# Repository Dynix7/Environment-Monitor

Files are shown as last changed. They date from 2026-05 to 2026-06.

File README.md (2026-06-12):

# Environment-Monitor
This is a board that serves as an environment sensor, recording the temperature, humidity, air pressure, brightness, and air quality of the area around it. It does this through the use of 5 sensors: TMP102AIDR, AHT20-F, BMP388, LTR303, and AGS10. The information can be displayed of the built in SSD1306 0.91 screen.
# Why I Made It
Not surprisingly I spend a lot of time sitting indoors in my room on my computer.  With this, I often have my door closed and sometimes the window open. I wanted a device that can monitor my room so I can make optimize my environment so if it detects that it's getting to hot (for example) I can open the window more or open my door. 

# Pictures

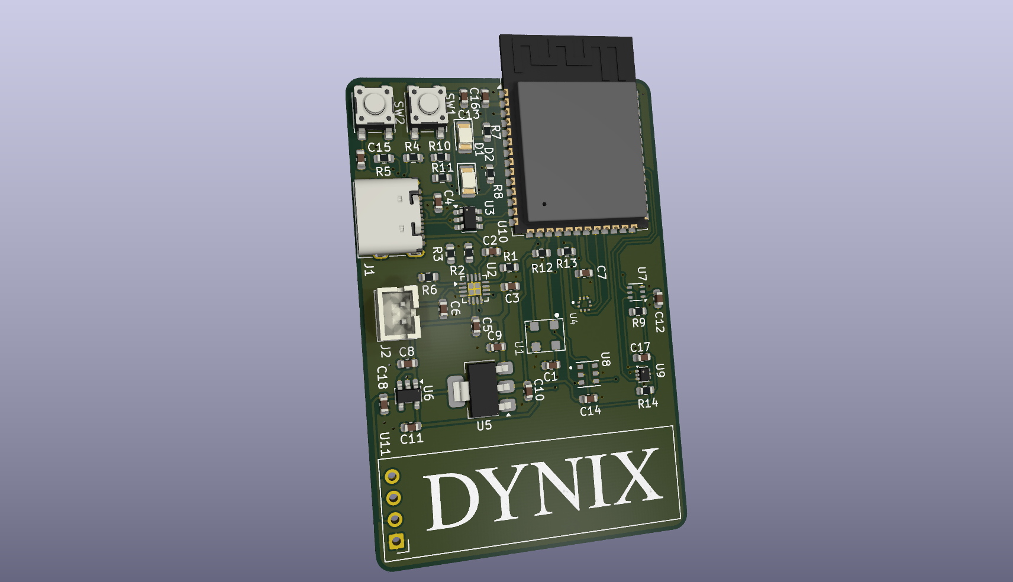
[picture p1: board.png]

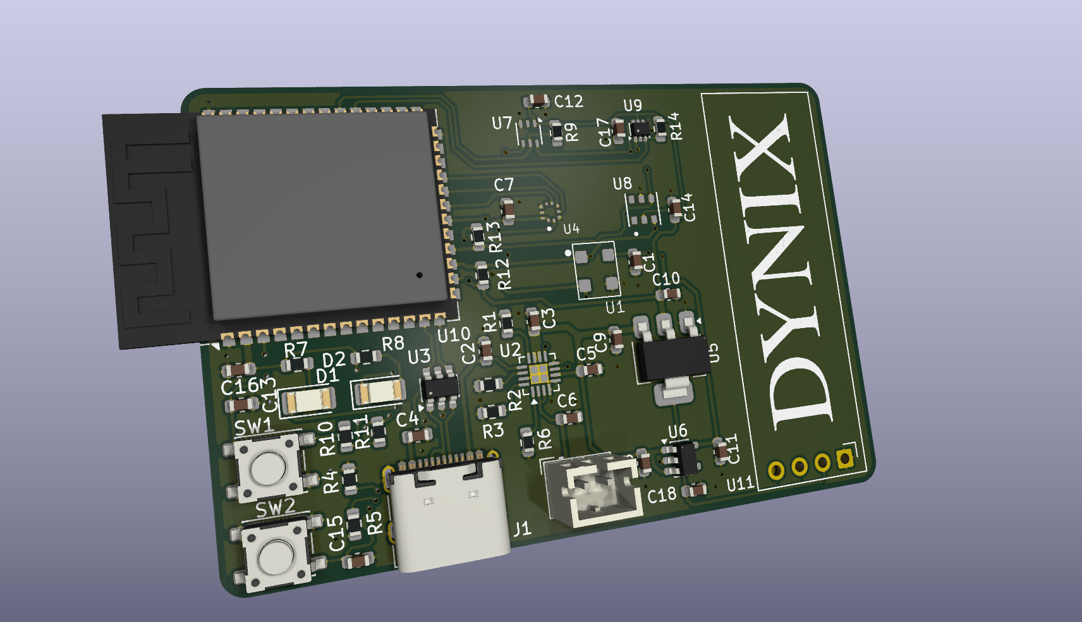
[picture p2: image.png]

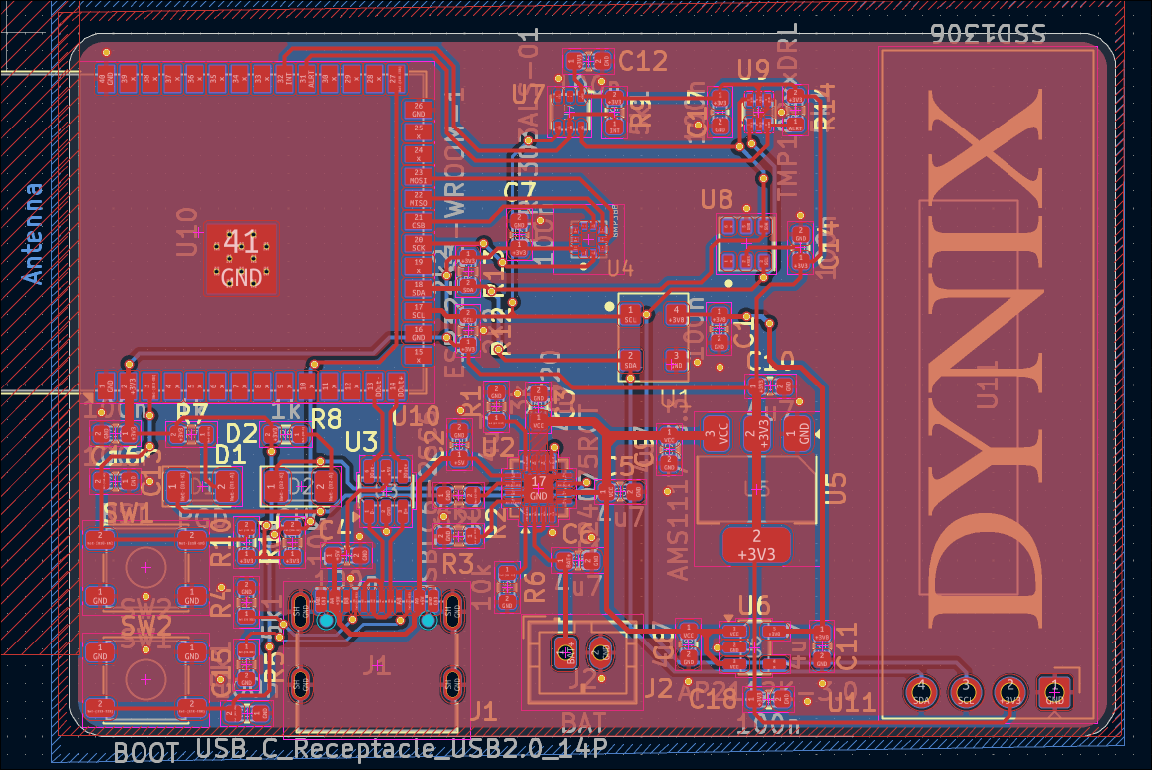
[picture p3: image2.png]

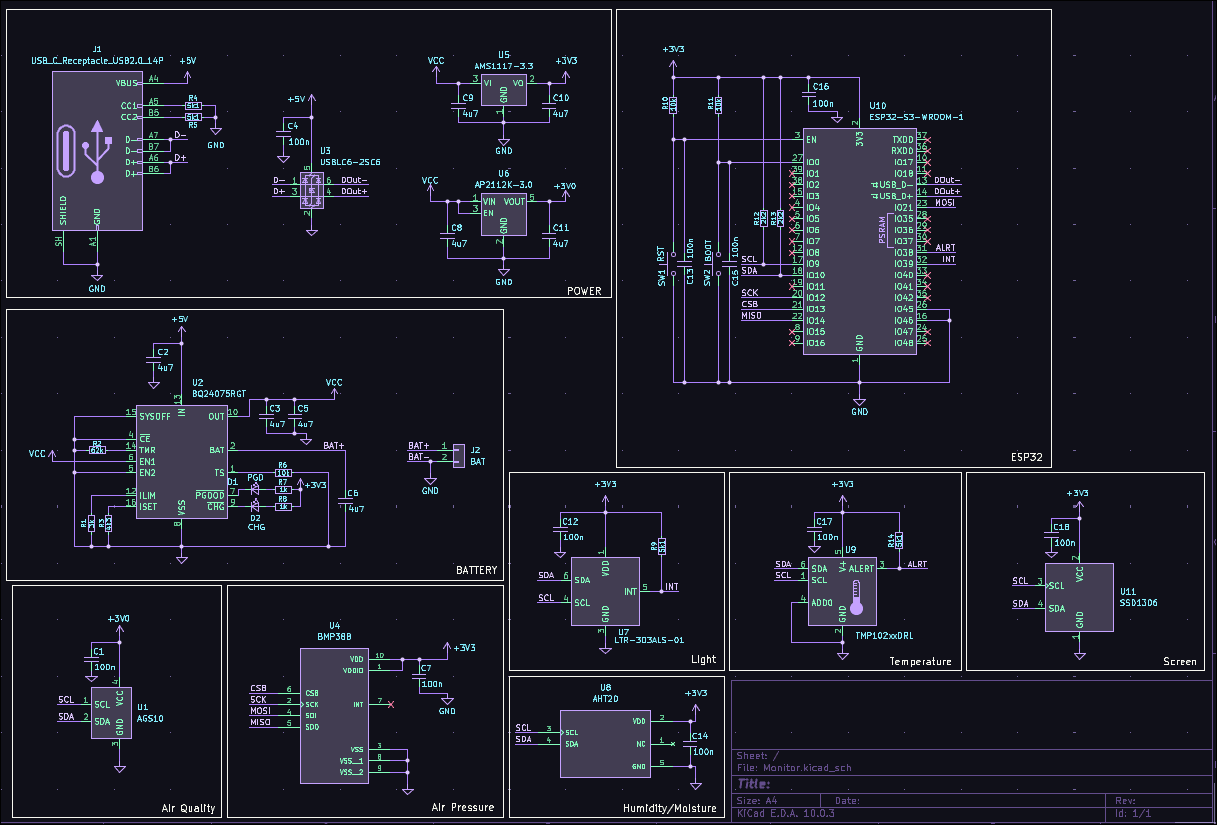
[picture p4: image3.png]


# BOM
|Name |Purpose |Quantity|Total Cost (USD)|Link |Distributor|
|---|---|---|---|---|---|
|3.7v Battery |Power when not plugged in | |6.57 |https://www.aliexpress.us/item/3256811644617885.html |Aliexpress |
|SSD1306 Display  |Displaying Measured Stats | |2.20 |https://www.aliexpress.us/item/3256808453793642.html |Aliexpress |
|JST Connector |Battery Connector | |0.67 |https://www.lcsc.com/product-detail/C131337.html |LCSC |
|USB C Receptacle |Programming and Power | |0.41 |https://www.lcsc.com/product-detail/C2988369.html |LCSC |
|4.3k Resistor |Configuration Resistor | |0.11 |https://www.lcsc.com/product-detail/C2930099.html |LCSC |
|62k Resistor |Configuration Resistor | |0.11 |https://www.lcsc.com/product-detail/C2907059.html |LCSC |
|3k Resistor |Configuration Resistor For BQ24075| |0.12 |https://www.lcsc.com/product-detail/C2907033.html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|LCSC |
|2.2k Resistor |I2C Pullups | |0.10 |https://www.lcsc.com/product-detail/C2907117.html |LCSC |
|1k Resistor |For LEDs | |0.10 |https://www.lcsc.com/product-detail/C2907002.html |LCSC |
|10k Resistor |Pull Ups | |0.10 |https://www.lcsc.com/product-detail/C2930027.html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|LCSC |
|5.1k Resistor |For USB CC1 and CC2 | |0.10 |https://www.lcsc.com/product-detail/C2907114.html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|LCSC |
|4.7uF Capacitor  |Decoupling Capacitor | |0.30 |https://www.lcsc.com/product-detail/C8032.html |LCSC |
|100nF Resistor |Decoupling | |0.25 |https://www.lcsc.com/product-detail/C5137636.html |LCSC |
|USBLC6-2SC6 |Protection for USB | |0.16 |https://www.lcsc.com/product-detail/C5261088.html |LCSC |
|BQ24075RGTR |Power Path and Battery Charging | |1.05 |https://www.lcsc.com/product-detail/C15464.html |LCSC |
|TPAP2112K-3.0TRG1|Power Regulator for AGS10 | |0.35 |https://www.lcsc.com/product-detail/C23380903.html |LCSC |
|AMS1117-3.3 |Power Regulator | |0.42 |https://www.lcsc.com/product-detail/C347222.html |LCSC |
|LTR-303ALS-01 |Light Sensor | |0.41 |https://www.lcsc.com/product-detail/C364577.html |LCSC |
|AGS10 |TVOC/Air Quality Sensor | |1.59 |https://www.lcsc.com/product-detail/C3012632.html |LCSC |
|BMP388 |Air Pressure Sensor | |2.81 |https://www.lcsc.com/product-detail/C779278.html |LCSC |
|TMP102AIDRLR |Accurate Temperature Sensor | |1.27 |https://www.lcsc.com/product-detail/C99269.html |LCSC |
|AHT20-F |Humidity Sensor |1 |0.76 |https://www.lcsc.com/product-detail/C3012622.html |LCSC |
|ESP32-S3 |Microcontroller for board |1 |5.25 |https://www.lcsc.com/product-detail/C2913205.html |LCSC |
|Stencil |Help With Soldering | |7.11 | |JLCPCB |
|PCB |Place Components On | |5.11 | |JLCPCB |

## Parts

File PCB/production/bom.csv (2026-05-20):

Designator | Footprint | Quantity | Value | LCSC Part #
C1, C12, C13, C14, C15, C16, C17, C18, C4, C7 | 0603 | 10 | 100n
C10, C11, C2, C3, C5, C6, C8, C9 | 0603 | 8 | 4u7
D1 | 1206 | 1 | PGD
D2 | 1206 | 1 | CHG
J1 | USB_C_Receptacle_G-Switch_GT-USB-7010ASV | 1 | USB_C_Receptacle_USB2.0_14P
J2 | JST_PH_B2B-PH-K_1x02_P2.00mm_Vertical | 1 | BAT
R1 | 0603 | 1 | 3k
R10, R11, R6 | 0603 | 3 | 10k
R12, R13 | 0603 | 2 | 2k2
R14, R4, R5, R9 | 0603 | 4 | 5k1
R2 | 0603 | 1 | 62k
R3 | 0603 | 1 | 4k3
R7, R8 | 0603 | 2 | 1k
SW1 | SW_SPST_PTS647_Sx38 | 1 | RST
SW2 | SW_SPST_PTS647_Sx38 | 1 | BOOT
U1 | AGS10 | 1 | AGS10
U10 | ESP32-S3-WROOM-1 | 1 | ESP32-S3-WROOM-1
U11 | ER_OLEDM0.91_1x-I2C | 1 | SSD1306
U2 | VQFN-16-1EP_3x3mm_P0.5mm_EP1.6x1.6mm | 1 | BQ24075RGT
U3 | SOT-23-6 | 1 | USBLC6-2SC6
U4 | XDCR_BMP388 | 1 | BMP388
U5 | SOT-223-3_TabPin2 | 1 | AMS1117-3.3
U6 | SOT-23-5 | 1 | AP2112K-3.0
U7 | Lite-On_LTR-303ALS-01 | 1 | LTR-303ALS-01
U8 | PSON100P300X300X110-6N | 1 | AHT20
U9 | SOT-563 | 1 | TMP102xxDRL

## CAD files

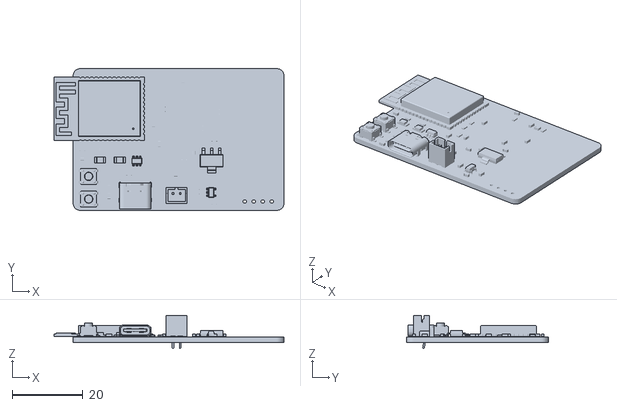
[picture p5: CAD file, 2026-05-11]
pcb.stl
64.9 x 40.0 x 9.40

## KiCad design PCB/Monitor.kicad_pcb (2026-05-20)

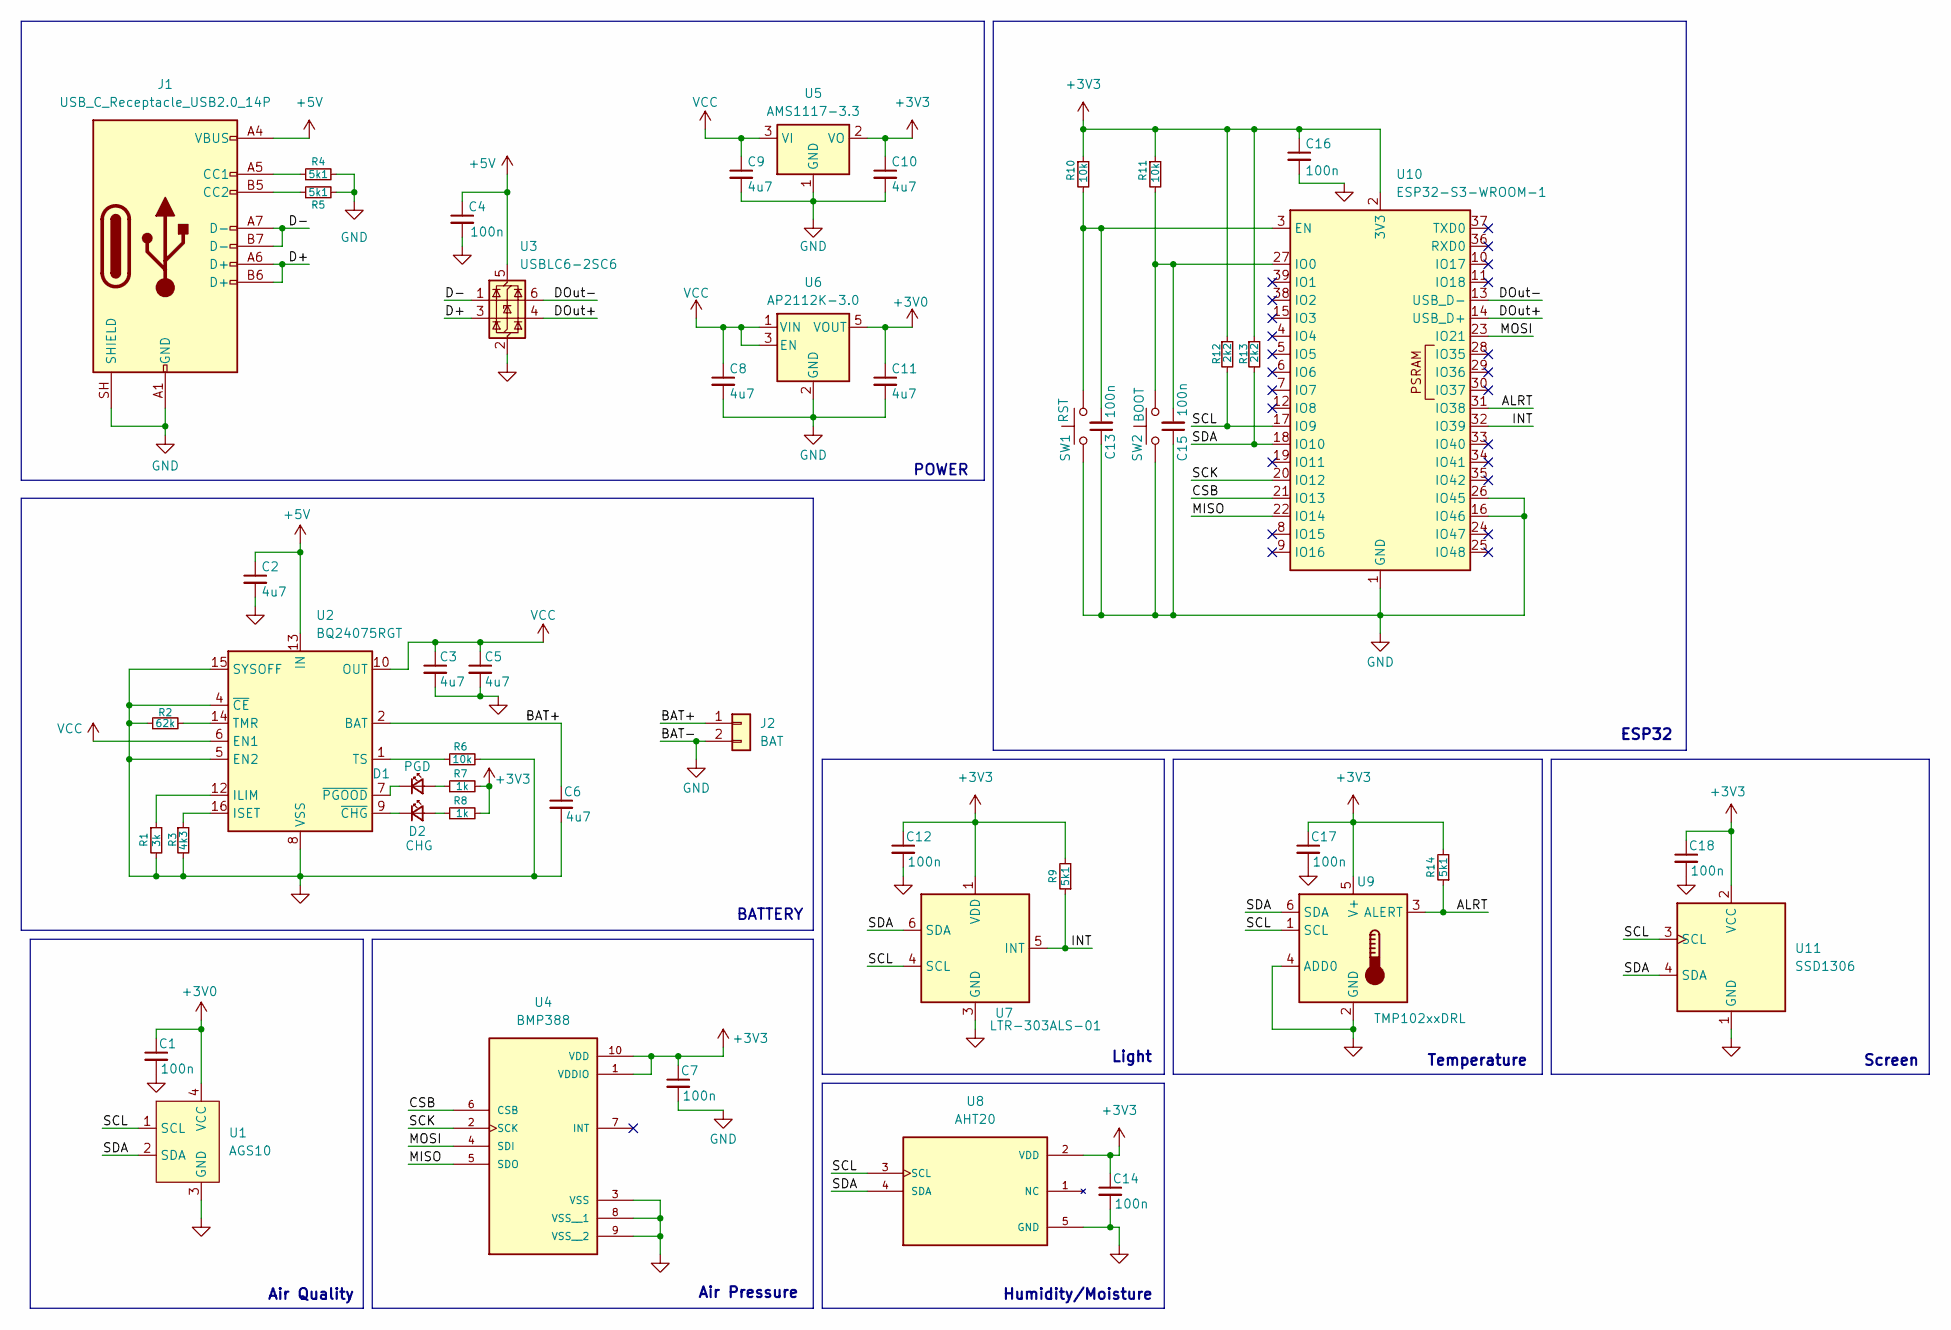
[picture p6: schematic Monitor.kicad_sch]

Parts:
C1, C4, C7, C12, C13, C14, C15, C16, C17, C18: 100n; C_0603_1608Metric
C2, C3, C5, C6, C8, C9, C10, C11: 4u7; C_0603_1608Metric
D1: PGD; LED_1206_3216Metric
D2: CHG; LED_1206_3216Metric
J1: USB_C_Receptacle_USB2.0_14P; USB_C_Receptacle_G-Switch_GT-USB-7010ASV
J2: BAT; JST_PH_B2B-PH-K_1x02_P2.00mm_Vertical
R1: 3k; R_0603_1608Metric
R2: 62k; R_0603_1608Metric
R3: 4k3; R_0603_1608Metric
R4, R5, R9, R14: 5k1; R_0603_1608Metric
R6, R10, R11: 10k; R_0603_1608Metric
R7, R8: 1k; R_0603_1608Metric
R12, R13: 2k2; R_0603_1608Metric
SW1: RST; SW_SPST_PTS647_Sx38
SW2: BOOT; SW_SPST_PTS647_Sx38
U1: AGS10
U2: BQ24075RGT; VQFN-16-1EP_3x3mm_P0.5mm_EP1.6x1.6mm
U3: USBLC6-2SC6; SOT-23-6
U4: BMP388; XDCR_BMP388; PARTREV 1.7
U5: AMS1117-3.3; SOT-223-3_TabPin2
U6: AP2112K-3.0; SOT-23-5
U7: LTR-303ALS-01; Lite-On_LTR-303ALS-01
U8: AHT20; PSON100P300X300X110-6N; PARTREV V1.0
U9: TMP102xxDRL; SOT-563
U10: ESP32-S3-WROOM-1
U11: SSD1306; ER_OLEDM0.91_1x-I2C

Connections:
+3V0: C1.1, C11.1, U1.4 (VCC), U6.5 (VOUT)
+3V3: C7.1, C10.1, C12.1, C14.1, C16.1, C17.1, C18.1, R7.2, R8.2, R9.2, R10.1, R11.1, R12.1, R13.1, R14.2, U4.1 (VDDIO), U4.10 (VDD), U5.2 (VO), U7.1 (VDD), U8.2 (VDD), U9.5 (V+), U10.2 (3V3), U11.2 (VCC)
+5V: C2.1, C4.1, J1.A4 (VBUS), J1.A9 (VBUS), J1.B4 (VBUS), J1.B9 (VBUS), U2.13 (IN), U3.5 (VBUS)
/ALRT: R14.1, U9.3 (ALERT), U10.31 (IO38)
/BAT+: C6.1, J2.1, U2.2 (BAT), U2.3 (BAT)
/CSB: U4.6 (CSB), U10.21 (IO13)
/D+: J1.A6 (D+), J1.B6 (D+), U3.3 (I/O2)
/D-: J1.A7 (D-), J1.B7 (D-), U3.1 (I/O1)
/DOut+: U3.4 (I/O2), U10.14 (USB_D+)
/DOut-: U3.6 (I/O1), U10.13 (USB_D-)
/INT: R9.1, U7.5 (INT), U10.32 (IO39)
/MISO: U4.5 (SDO), U10.22 (IO14)
/MOSI: U4.4 (SDI), U10.23 (IO21)
/SCK: U4.2 (SCK), U10.20 (IO12)
/SCL: R12.2, U1.1 (SCL), U7.4 (SCL), U8.3 (SCL), U9.1 (SCL), U10.17 (IO9), U11.3 (SCL)
/SDA: R13.2, U1.2 (SDA), U7.6 (SDA), U8.4 (SDA), U9.6 (SDA), U10.18 (IO10), U11.4 (SDA)
GND: C1.2, C2.2, C3.2, C4.2, C5.2, C6.2, C7.2, C8.2, C9.2, C10.2, C11.2, C12.2, C13.1, C14.2, C15.1, C16.2, C17.2, C18.2, J1.A1 (GND), J1.A12 (GND), J1.B1 (GND), J1.B12 (GND), J1.SH (SHIELD), J2.2, R1.2, R2.1, R3.2, R4.2, R5.2, R6.2, SW1.1, SW2.1, U1.3 (GND), U2.4 (~CE), U2.5 (EN2), U2.8 (VSS), U2.15 (SYSOFF), U2.17 (VSS), U3.2 (GND), U4.3 (VSS), U4.8 (VSS__1), U4.9 (VSS__2), U5.1 (GND), U6.2 (GND), U7.3 (GND), U8.5 (GND), U9.2 (GND), U9.4 (ADD0), U10.1 (GND), U10.16 (IO46), U10.26 (IO45), U10.40 (GND), U10.41 (GND), U11.1 (GND)
unnamed: D1.2 (A), R7.1
unnamed: D1.1 (K), U2.7 (~PGOOD)
unnamed: D2.2 (A), R8.1
unnamed: D2.1 (K), U2.9 (~CHG)
unnamed: J1.A5 (CC1), R4.1
unnamed: J1.B5 (CC2), R5.1
unnamed: R1.1, U2.12 (ILIM)
unnamed: R3.1, U2.16 (ISET)
unnamed: R2.2, U2.14 (TMR)
unnamed: R6.1, U2.1 (TS)
unnamed: C13.2, R10.2, SW1.2, U10.3 (EN)
unnamed: C15.2, R11.2, SW2.2, U10.27 (IO0)
VCC: C3.1, C5.1, C8.1, C9.1, U2.6 (EN1), U2.10 (OUT), U2.11 (OUT), U5.3 (VI), U6.1 (VIN), U6.3 (EN)

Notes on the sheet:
Screen
Humidity/Moisture
Light
Air Pressure
ESP32
Air Quality
POWER
BATTERY
Temperature

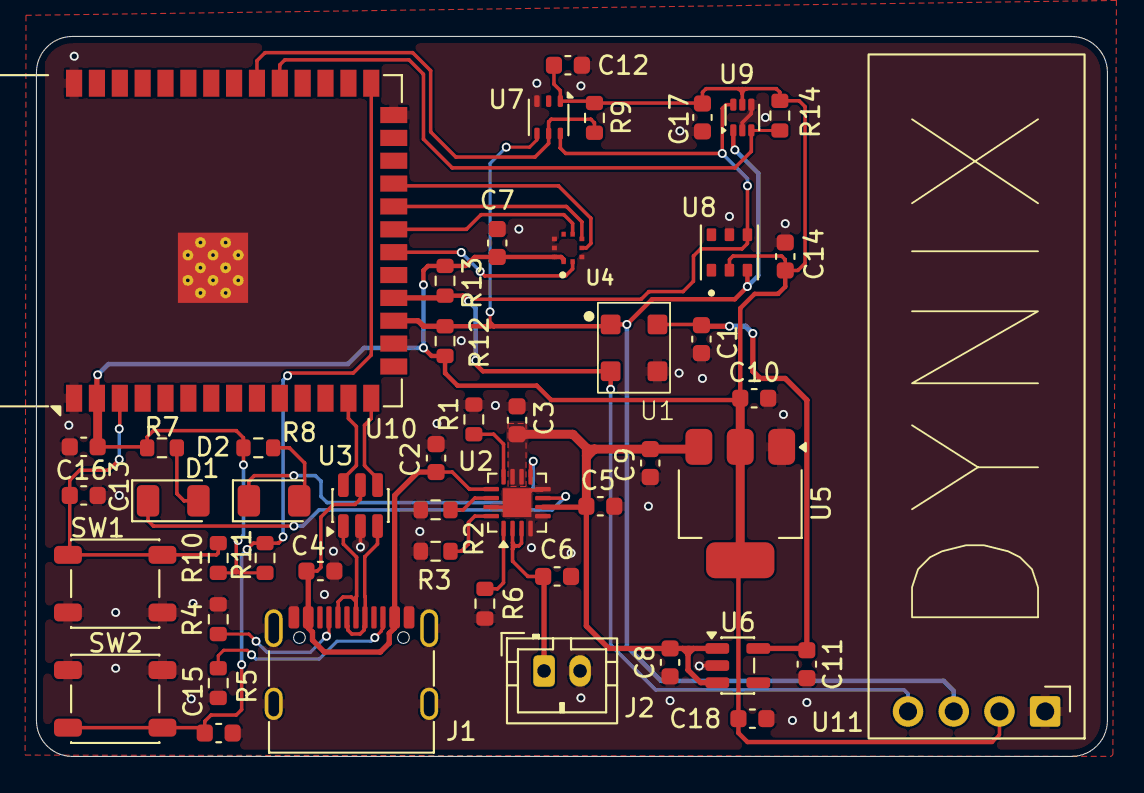
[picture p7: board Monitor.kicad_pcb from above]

Board: 2 copper layers, 59.5 x 40.0 mm, 49 parts (0 on the bottom side), 30 nets.

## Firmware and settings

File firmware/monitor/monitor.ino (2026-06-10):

#include <Arduino.h>
#include <Wire.h>

#include <AGS10.h>
#include <Adafruit_SSD1306.h>
#include <Adafruit_Sensor.h>
#include "Adafruit_BMP3XX.h"
#include <Adafruit_AHTX0.h>
#include "Adafruit_LTR329_LTR303.h"
#include <SparkFunTMP102.h>


#include "config.hpp"

struct totalData data;


Adafruit_SSD1306 SCREEN(SCREEN_WIDTH, SCREEN_HEIGHT, SCREEN_WIRE, OLED_RESET);
AGS10 AGSSensor = AGS10();
Adafruit_BMP3XX BMPSensor;
Adafruit_AHTX0 AHT20;
Adafruit_LTR303 LTR = Adafruit_LTR303();
TMP102 TMP;

// Prototypes
void initScreen();
void updateScreen();

void initAGS();
void initBMP();
void initAHT();
void initLTR();
void initTMP();

void readAllData();



void setup() {
    Serial.begin(115200);

    pinMode(CSB, OUTPUT);
    pinMode(ALRT, INPUT);
    
    Wire.begin(SDA_PIN, SCL_PIN);
    Wire.setClock(400000);


    initScreen();

    initAGS();
    initBMP();
    initAHT();
    initLTR();
    initTMP();
}


void loop() {
    readAllData();
    updateScreen();

    delay(2000);
}

void initScreen() {
    SCREEN.begin(SSD1306_SWITCHCAP, SCREEN_ADDRESS);
    SCREEN.clearDisplay();
    SCREEN.setTextSize(2);
    SCREEN.setTextColor(SSD1306_WHITE);

    SCREEN.print("Starting...");
    SCREEN.display();
}

void updateScreen() {
    SCREEN.clearDisplay();
    SCREEN.setTextSize(1);
    SCREEN.setCursor(0, 0);

    SCREEN.print("Temperature: ");
    SCREEN.println(data.temperature);

    SCREEN.print("Humidity: ");
    SCREEN.println(data.humidity);

    SCREEN.print("TVOC: ");
    SCREEN.println(data.TVOC);

    SCREEN.print("Pressure: ");
    SCREEN.println(data.pressure);

    SCREEN.print("Altitude: ");
    SCREEN.println(data.altitude);

    SCREEN.print("Visible + IR: ");
    SCREEN.println(data.visbleAndIR);

    SCREEN.print("IR: ");
    SCREEN.println(data.IR);

    SCREEN.display();
}

void initAGS() {
    AGSSensor.begin();
    AGSSensor.calibrateFact();
}

void initBMP() {
    if(!BMPSensor.begin_SPI(CSB, SCK, MISO, MOSI)) {
        Serial.print("BMP Error");
    }

    BMPSensor.setTemperatureOversampling(BMP3_OVERSAMPLING_8X);
    BMPSensor.setPressureOversampling(BMP3_OVERSAMPLING_4X);
    BMPSensor.setIIRFilterCoeff(BMP3_IIR_FILTER_COEFF_3);
    BMPSensor.setOutputDataRate(BMP3_ODR_50_HZ);
}

void initAHT() {
    if (!AHT20.begin()) {
        Serial.print("AHT Error");
    }
}

void initLTR() {
    if (!LTR.begin(&Wire)) {
        Serial.print("LTR Error");
    }

    LTR.setGain(LTR3XX_GAIN_1);
    LTR.setIntegrationTime(LTR3XX_INTEGTIME_150);
    LTR.setMeasurementRate(LTR3XX_MEASRATE_150);
}

void initTMP() {
    if (!TMP.begin()) {
        Serial.print("TMP Error");
    }
    TMP.setConversionRate(1);
    TMP.setExtendedMode(0);
}

void readAllData() {

    //BMP388
    BMPSensor.performReading();
    data.pressure = (BMPSensor.pressure / 100.0);
    data.altitude = BMPSensor.readAltitude(SEALEVELPRESSURE_HPA);

    //AHT20
    sensors_event_t humidity, temp;
    AHT20.getEvent(&humidity, &temp);
    data.humidity = humidity.relative_humidity;

    //AGOS
    data.TVOC = AGSSensor.readTVOC();

    //TMP
    TMP.wakeup();
    data.temperature = TMP.readTempF();
    TMP.sleep();

    // LTR
    if (LTR.newDataAvailable()) {
        LTR.readBothChannels(data.visbleAndIR, data.IR);
    }


}

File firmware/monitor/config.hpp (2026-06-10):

#ifndef CONFIG_H
#define CONFIG_H

// Pinout
#define SDA_PIN 10
#define SCL_PIN 9

#define SCK 12
#define CSB 13
#define MISO 14
#define MOSI 21

#define ALRT 38
#define INTR 39


// Screen
#define SCREEN_WIDTH 128
#define SCREEN_HEIGHT 32
#define OLED_RESET -1 
#define SCREEN_ADDRESS 0x3C   
#define SCREEN_WIRE &Wire

#define SEALEVELPRESSURE_HPA (1013.25)

struct totalData {
    //AGS10
    int TVOC = 0;

    // BMP388
    float pressure = 0.0;
    float altitude = 0.0;
    
    //AHT20
    float humidity = 0.0;

    //TMP102
    float temperature = 0.0;

    //LTR303
    uint16_t visbleAndIR = 0;
    uint16_t IR = 0;
};

#endif

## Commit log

2026-05-09 Start of Schematic
    [Monitor.kicad_pcb, Monitor.kicad_sch]
2026-05-09 Most of Schematic
    [Monitor.kicad_sch]
2026-05-11 Finish PCB + pictures + BOM
    [Monitor.kicad_pcb, Monitor.kicad_sch, pcb.stl]
2026-05-20 Update BOM and better labeling
    [Monitor.kicad_pcb, Monitor.kicad_sch]
2026-05-20 Change .gitignore that ignored my BOM
    [BOM.csv, bom.csv, designators.csv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]
2026-06-12 Add Schmatic Image and duplicated gerber file for root
